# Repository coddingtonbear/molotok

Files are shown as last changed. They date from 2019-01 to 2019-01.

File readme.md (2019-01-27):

# Molotok: ATtiny85-based WS2812b Controller

I wake up both way before my partner and way before sunrise most mornings and need to see in my wardrobe to pick out clothes for the day.
To do this, I have to carefully aim my phone's flashlight into the closet, and, given that the process of putting on clothes generally requires that I have free hands, I've dropped my phone many times making a great deal of partner-waking noise.
So, I thought, why don't I fix this? I know I have at least a meter of neopixels available; can't basically any problem be fixed with a microcontroller and a bunch of leds?  This is that.

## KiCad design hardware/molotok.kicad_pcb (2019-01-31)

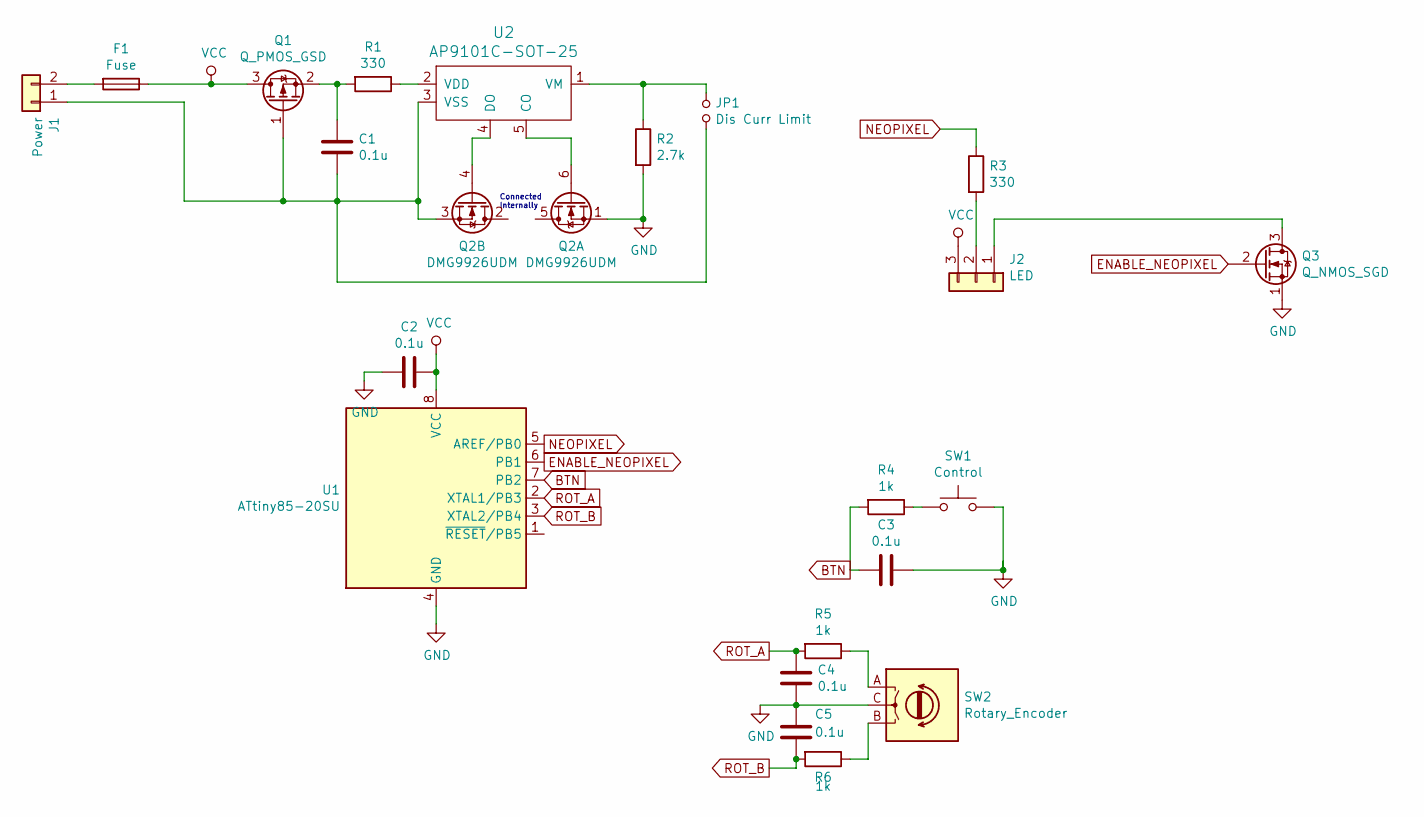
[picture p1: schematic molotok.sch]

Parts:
C1, C2, C3, C4, C5: 0.1u; 0805_Milling
F1: Fuse; R_1206_3216Metric_Pad1.42x1.75mm_HandSolder
J1: Power; JST_XH_B02B-XH-A_02x2.50mm_Straight_LargePads
J2: LED; JST_XH_B03B-XH-A_03x2.50mm_Straight_LargePads
JP1: Dis Curr Limit; SolderJumper-2_P1.3mm_Open_RoundedPad1.0x1.5mm
Q1: Q_PMOS_GSD; SuperSOT-3
Q2: DMG9926UDM; SOT-23-6_Handsoldering
Q3: Q_NMOS_SGD; PSMN5R4-25YLD
R1, R3: 330; 0805_Milling
R2: 2.7k; 0805_Milling
R4, R5, R6: 1k; 0805_Milling
SW1: Control; SMD_RED_TACTILE_SWITCH
SW2: Rotary_Encoder; PES12
U1: ATtiny85-20SU; SOIJ-8_5.3x5.3mm_P1.27mm
U2: AP9101C-SOT-25; SOT-23-5_HandSoldering

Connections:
BTN: C3.1, R4.2, U1.7 (PB2)
ENABLE_NEOPIXEL: Q3.2 (G), U1.6 (PB1)
GND: C2.1, C3.2, C4.2, C5.1, Q2.1 (S), Q3.1 (S), R2.2, SW1.2, SW2.C, U1.4 (GND)
NEOPIXEL: R3.1, U1.5 (AREF/PB0)
unnamed: C1.1, Q1.2 (S), R1.2
unnamed: C1.2, J1.1, JP1.2, Q1.1 (G), Q2.3 (S), U2.3 (VSS)
unnamed: F1.2, J1.2
unnamed: J2.1, Q3.3 (D)
unnamed: J2.2, R3.2
unnamed: JP1.1, R2.1, U2.1 (VM)
unnamed: Q2.4 (G), U2.4 (DO)
unnamed: Q2.6 (G), U2.5 (CO)
unnamed: R1.1, U2.2 (VDD)
unnamed: R4.1, SW1.1
unnamed: R5.1, SW2.A
unnamed: R6.1, SW2.B
ROT_A: C4.1, R5.2, U1.2 (XTAL1/PB3)
ROT_B: C5.2, R6.2, U1.3 (XTAL2/PB4)
VCC: C2.2, F1.1, J2.3, Q1.3 (D), U1.8 (VCC)

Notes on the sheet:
Connected Internally

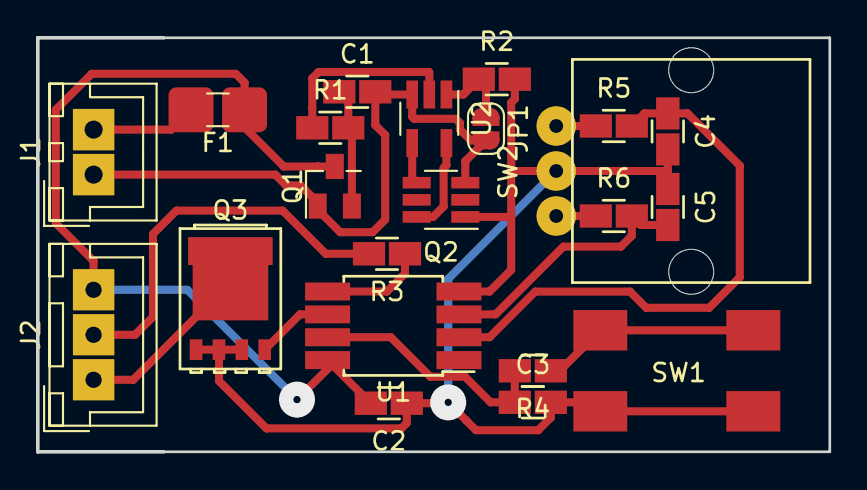
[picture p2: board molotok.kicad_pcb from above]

Board: 2 copper layers, 44.0 x 23.0 mm, 22 parts (0 on the bottom side), 19 nets.

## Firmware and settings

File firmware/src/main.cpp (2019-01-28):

#include <Arduino.h>
#include <Adafruit_NeoPixel.h>
#include <JC_Button.h>

#define NUM_LEDS 60

#define LED_PIN 0
#define BUTTON 2
#define ROT_A 3
#define ROT_B 4

#define INCREMENT 10;

Adafruit_NeoPixel leds = Adafruit_NeoPixel(
  NUM_LEDS, LED_PIN, NEO_GRB + NEO_KHZ800);

bool enabled = false;

int16_t red = 50;
int16_t green = 50;
int16_t blue = 50;

bool wasLowLast = false;
bool encoderInput = false;
bool cw = false;

Button button = Button(BUTTON);

void setup() {
  GIMSK = 0b00100000;
  PCMSK = 0b00001000;

  pinMode(ROT_A, INPUT_PULLUP);
  pinMode(ROT_B, INPUT_PULLUP);

  leds.begin();
  button.begin();

  delay(500);

  for(int i=0; i < NUM_LEDS; i++){
    leds.setPixelColor(i, leds.Color(0, 0, 0));
  }
  leds.show();
  sei();

  delay(500);
}

void loop() {
  button.read();

  if (enabled) {
    for(int i=0; i < NUM_LEDS; i++){
      leds.setPixelColor(i, leds.Color(red,green,blue));
    }
    leds.show();
  }
  if(button.wasReleased()) {
    enabled = !enabled;

    if(!enabled) {
      for(int i=0; i < NUM_LEDS; i++){
        leds.setPixelColor(i, leds.Color(0, 0, 0));
      }
      leds.show();
    }
  }
  if(encoderInput) {
    encoderInput = false;

    if(cw) {
      red += INCREMENT;
      if(red >= 255) {
        red = 255;
      }
      green += INCREMENT;
      if(green >= 255) {
        green = 255;
      }
      blue += INCREMENT;
      if(blue >= 255) {
        blue = 255;
      }
    } else {
      red -= INCREMENT;
      if(red < 0) {
        red = 0;
      }
      green -= INCREMENT;
      if(green < 0) {
        green = 0;
      }
      blue -= INCREMENT;
      if(blue < 0) {
        blue = 0;
      }
    }
  }
}

ISR(PCINT0_vect)
{
  if(!(PINB & 0b00001000)) {
    wasLowLast = true;
  }

  if(wasLowLast) {
    encoderInput = true;
    wasLowLast = false;
    if(PINB & 0b00010000) {
      cw = true;
    } else {
      cw = false;
    }
  }
}

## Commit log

2019-01-27 And so it begins...
    [molotok.kicad_pcb, molotok.sch]
2019-01-27 Reversing mosfet orientation to be correct.
    [molotok.kicad_pcb, molotok.sch]
2019-01-27 Use a rotary encoder instead of a potentiometer for control.
    [molotok.kicad_pcb, molotok.sch]
2019-01-28 Adding firmware.
    [molotok.sch]
2019-01-31 Adding fuse.
    [molotok.kicad_pcb, molotok.sch]
